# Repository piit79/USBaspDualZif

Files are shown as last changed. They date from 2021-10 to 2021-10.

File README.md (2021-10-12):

# USBaspDualZif

USB in-circuit programmer for Atmel AVR controllers based on USBasp by Thomas Fischl (https://www.fischl.de/usbasp/).

It adds the following extra features:

  * Dual ZIF sockets for ATMega32A-PU and ATMega328p-PU
  * One Cherry MX-compatible switch that acts as the Enter key
  * USB-C socket

Uses mostly SMD components for street cred.

Modified firmware: https://github.com/piit79/USBasp/tree/USBaspDualZif

Released under the [GNU General Public License v2.0](https://raw.githubusercontent.com/piit79/USBaspDualZif/main/LICENSE) (as it's based on USBasp)

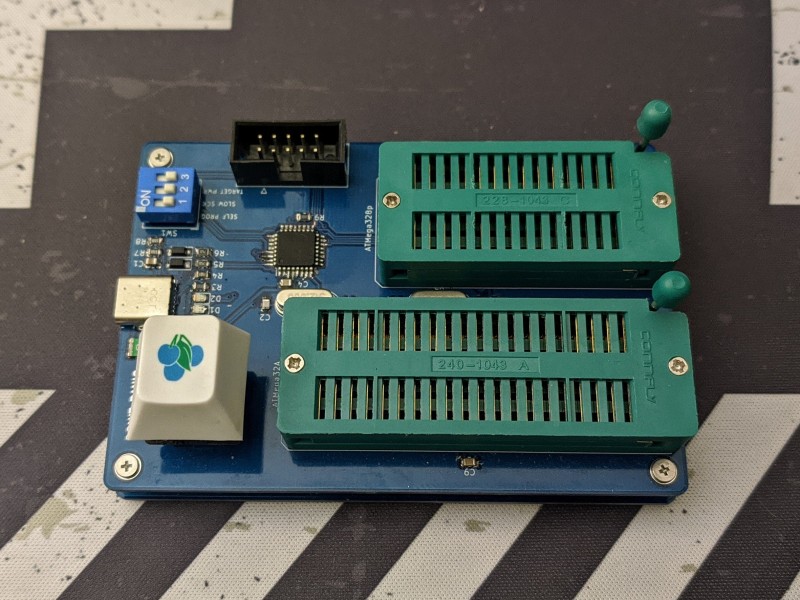
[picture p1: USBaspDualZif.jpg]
USBaspDualZif photo


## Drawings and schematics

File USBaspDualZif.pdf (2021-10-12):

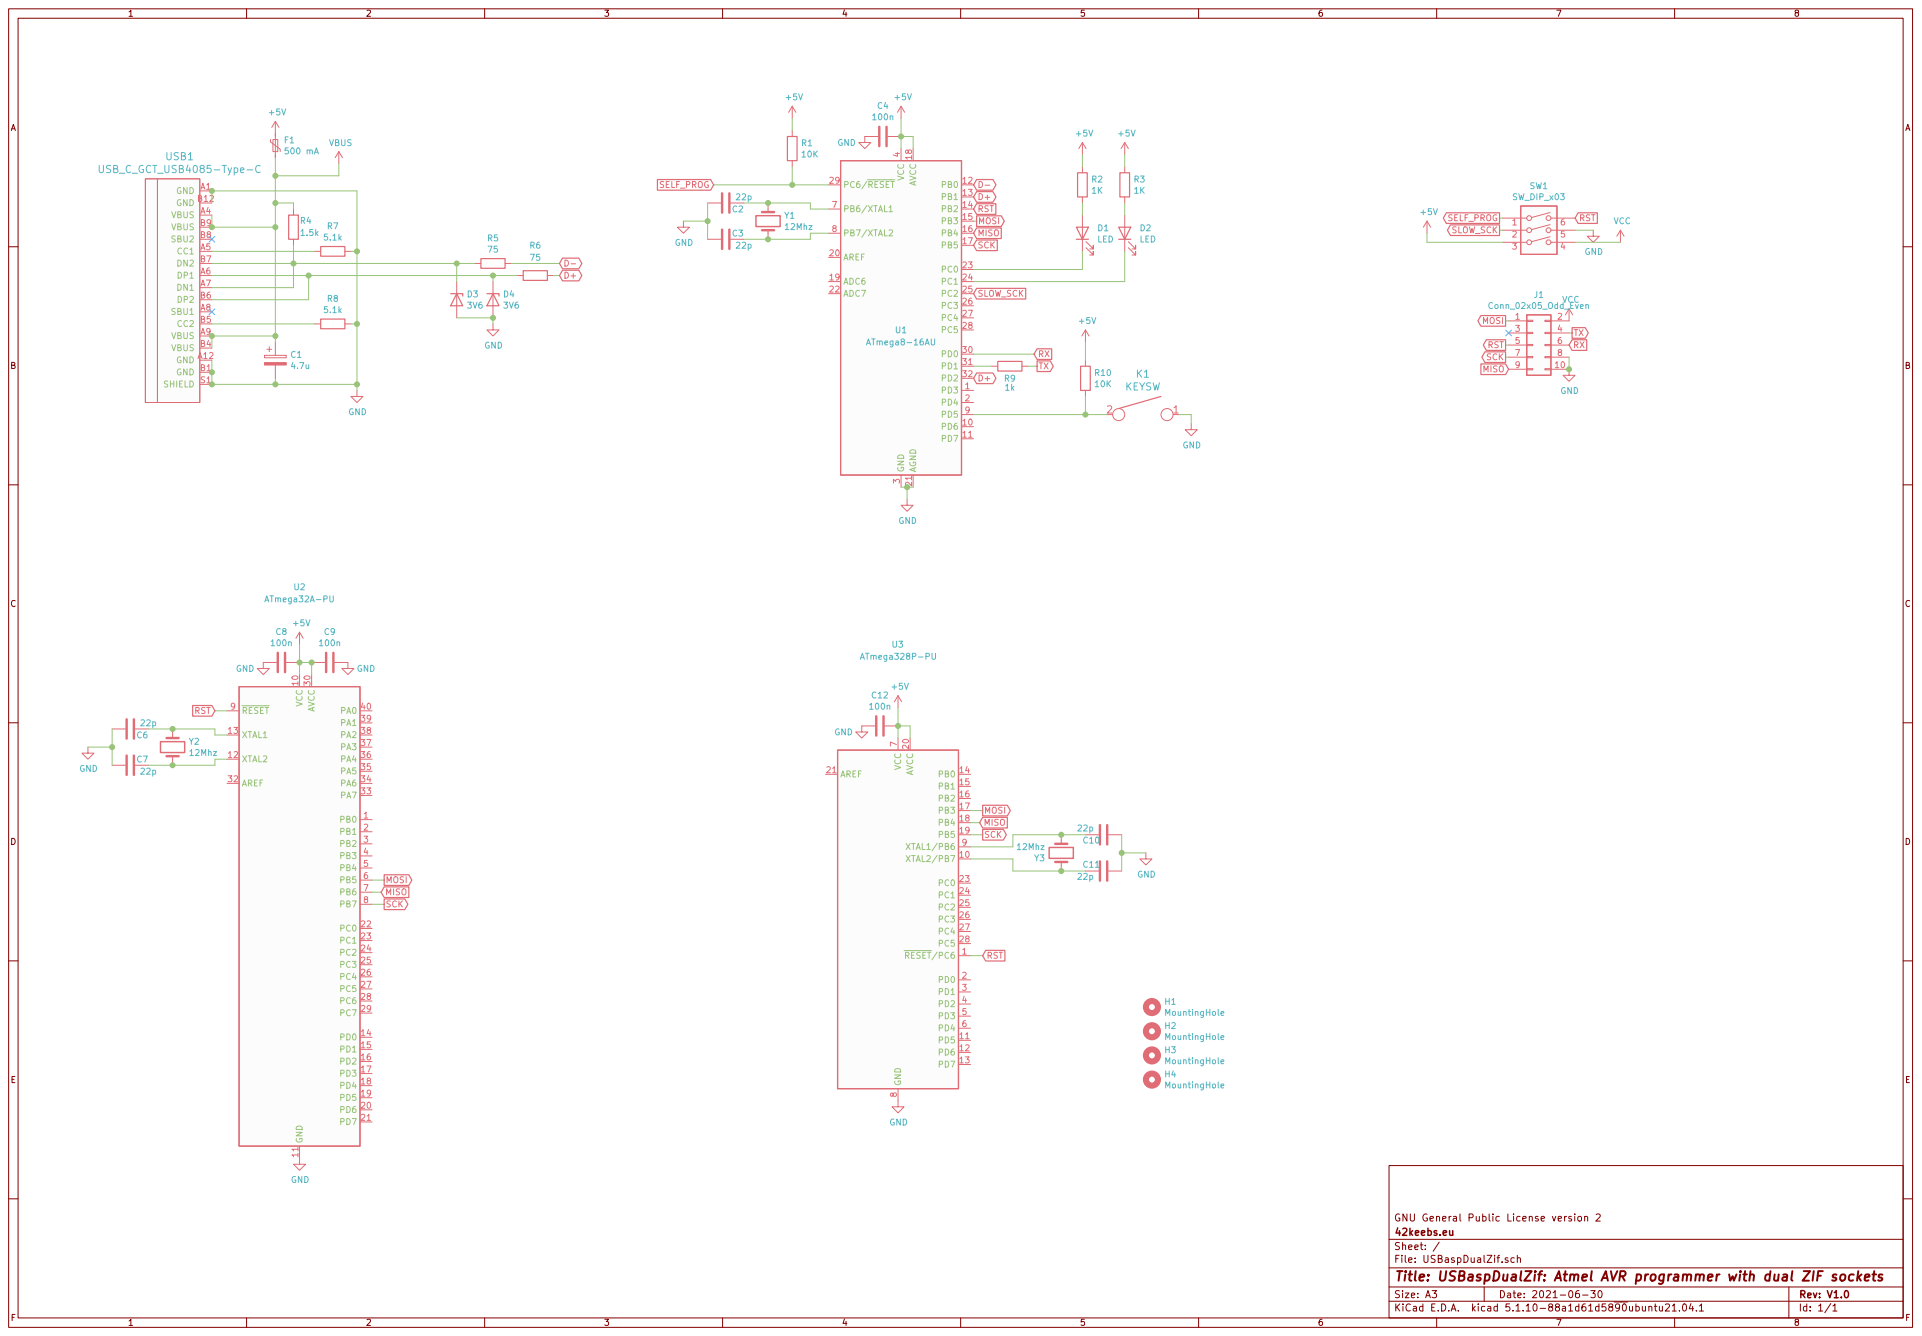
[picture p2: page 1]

File: USBaspDualZif.sch Sheet: / 42keebs.eu GNU General Public License version 2

Id: 1/1 Title: USBaspDualZif: Atmel AVR programmer with dual ZIF sockets

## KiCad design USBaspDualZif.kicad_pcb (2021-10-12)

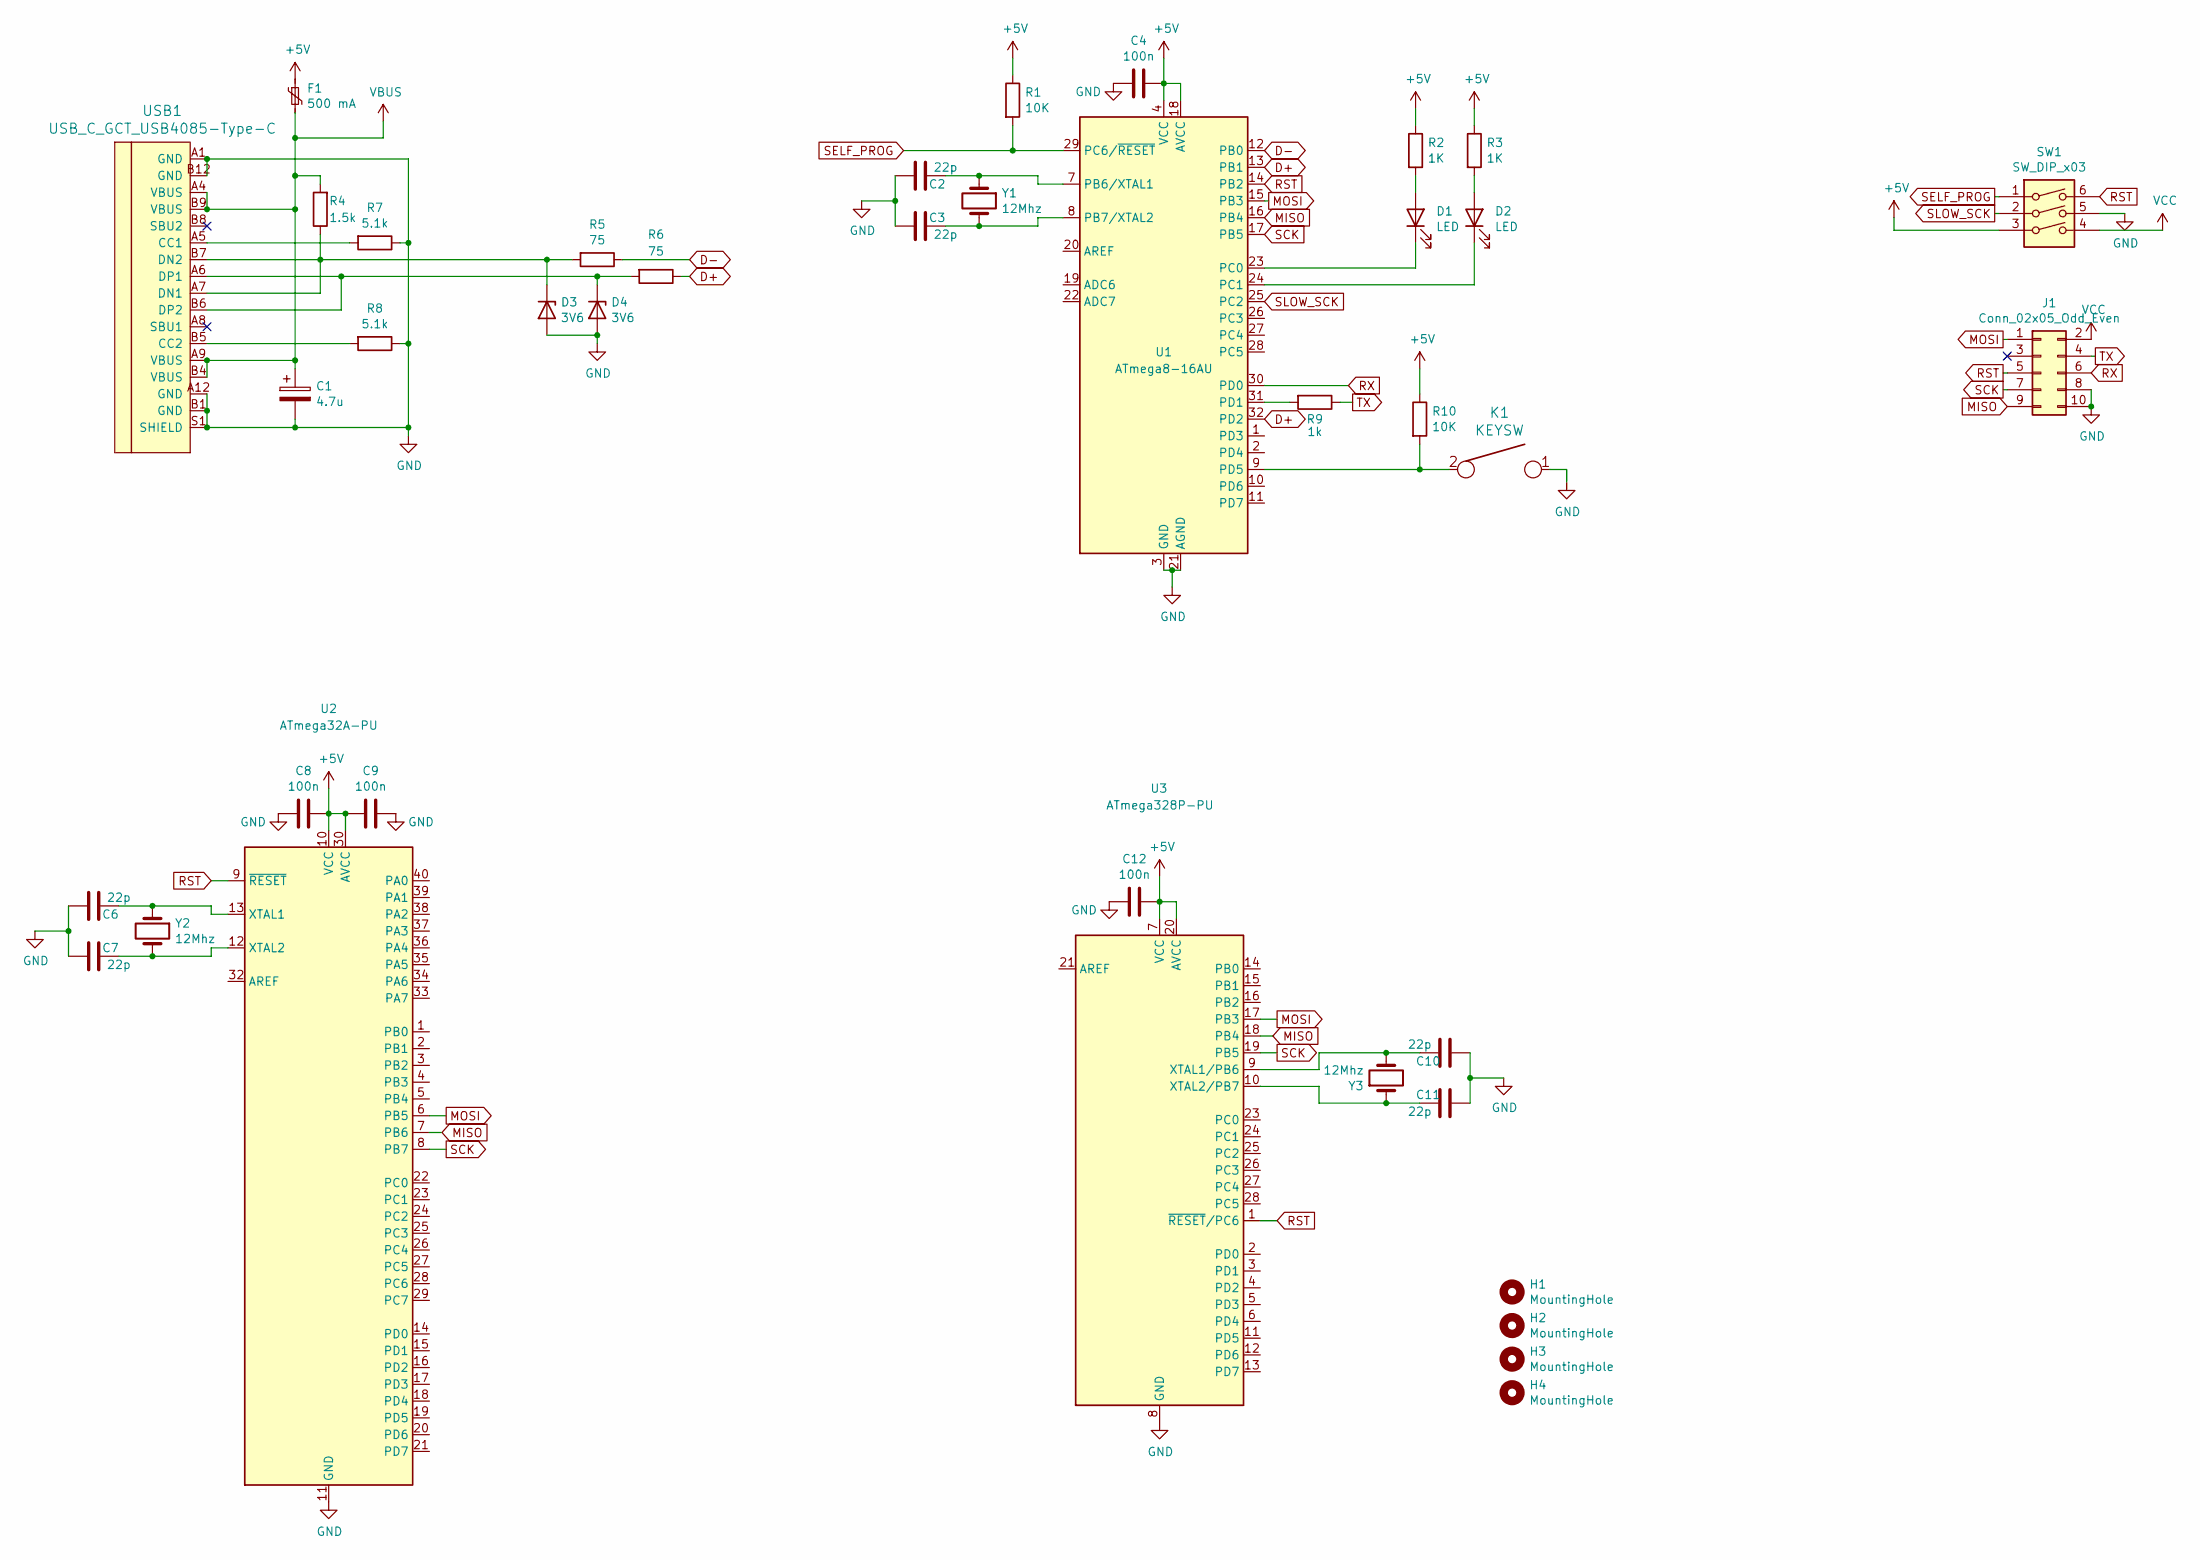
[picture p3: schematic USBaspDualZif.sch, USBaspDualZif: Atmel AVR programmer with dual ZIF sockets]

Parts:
C1: 4.7u; C_0805_2012Metric
C2, C3, C6, C7, C10, C11: 22p; C_0805_2012Metric
C4, C8, C9, C12: 100n; C_0805_2012Metric
D1, D2: LED; LED_0805_2012Metric
D3, D4: 3V6; D_SOD-123
F1: 500 mA; Fuse_1812_4532Metric
H1, H2, H3, H4: MountingHole; MountingHole_2.2mm_M2_Pad
J1: Conn_02x05_Odd_Even; IDC-Header_2x05_P2.54mm_Vertical
K1: KEYSW; SW_Cherry_MX1A_1.00u_PCB-NOSCREEN
R1, R10: 10K; R_0805_2012Metric
R2, R3: 1K; R_0805_2012Metric
R4: 1.5k; R_0805_2012Metric
R5, R6: 75; R_0805_2012Metric
R7, R8: 5.1k; R_0805_2012Metric
R9: 1k; R_0805_2012Metric
SW1: SW_DIP_x03; SW_DIP_SPSTx03_Slide_9.78x9.8mm_W7.62mm_P2.54mm
U1: ATmega8-16AU; TQFP-32_7x7mm_P0.8mm
U2: ATmega32A-PU; 40tex600
U3: ATmega328P-PU; 28tex600
USB1: USB_C_GCT_USB4085-Type-C; USB_C_GCT_USB4085-offset-pads
Y1, Y2, Y3: 12Mhz; Crystal_HC49-4H_Vertical

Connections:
+5V: C4.1, C8.1, C9.2, C12.1, F1.1, R1.1, R2.1, R3.1, R10.1, SW1.3, U1.4 (VCC), U1.6 (VCC), U1.18 (AVCC), U2.10 (VCC), U2.30 (AVCC), U3.7 (VCC), U3.20 (AVCC)
D+: R6.1, U1.13 (PB1), U1.32 (PD2)
D-: R5.1, U1.12 (PB0)
GND: C1.2, C2.2, C3.2, C4.2, C6.2, C7.2, C8.2, C9.1, C10.2, C11.2, C12.2, D3.2 (A), D4.2 (A), J1.8, J1.10, K1.1, R7.1, R8.1, SW1.5, U1.3 (GND), U1.5 (GND), U1.21 (AGND), U2.11 (GND), U2.31 (GND), U3.8 (GND), U3.22 (GND), USB1.A1 (GND), USB1.A12 (GND), USB1.B1 (GND), USB1.B12 (GND), USB1.S1 (SHIELD)
MISO: J1.9, U1.16 (PB4), U2.7 (PB6), U3.18 (PB4)
MOSI: J1.1, U1.15 (PB3), U2.6 (PB5), U3.17 (PB3)
unnamed: C2.1, U1.7 (PB6/XTAL1), Y1.1
unnamed: C3.1, U1.8 (PB7/XTAL2), Y1.2
unnamed: C6.1, U2.13 (XTAL1), Y2.1
unnamed: C7.1, U2.12 (XTAL2), Y2.2
unnamed: C10.1, U3.9 (XTAL1/PB6), Y3.2
unnamed: C11.1, U3.10 (XTAL2/PB7), Y3.1
unnamed: D1.1 (K), U1.23 (PC0)
unnamed: D1.2 (A), R2.2
unnamed: D2.1 (K), U1.24 (PC1)
unnamed: D2.2 (A), R3.2
unnamed: D3.1 (K), R4.1, R5.2, USB1.A7 (DN1), USB1.B7 (DN2)
unnamed: D4.1 (K), R6.2, USB1.A6 (DP1), USB1.B6 (DP2)
unnamed: K1.2, R10.2, U1.9 (PD5)
unnamed: R7.2, USB1.A5 (CC1)
unnamed: R8.2, USB1.B5 (CC2)
unnamed: R9.2, U1.31 (PD1)
RST: J1.5, SW1.6, U1.14 (PB2), U2.9 (~RESET), U3.1 (~RESET~/PC6)
RX: J1.6, U1.30 (PD0)
SCK: J1.7, U1.17 (PB5), U2.8 (PB7), U3.19 (PB5)
SELF_PROG: R1.2, SW1.1, U1.29 (PC6/~RESET)
SLOW_SCK: SW1.2, U1.25 (PC2)
TX: J1.4, R9.1
VBUS: C1.1, F1.2, R4.2, USB1.A4 (VBUS), USB1.A9 (VBUS), USB1.B4 (VBUS), USB1.B9 (VBUS)
VCC: J1.2, SW1.4

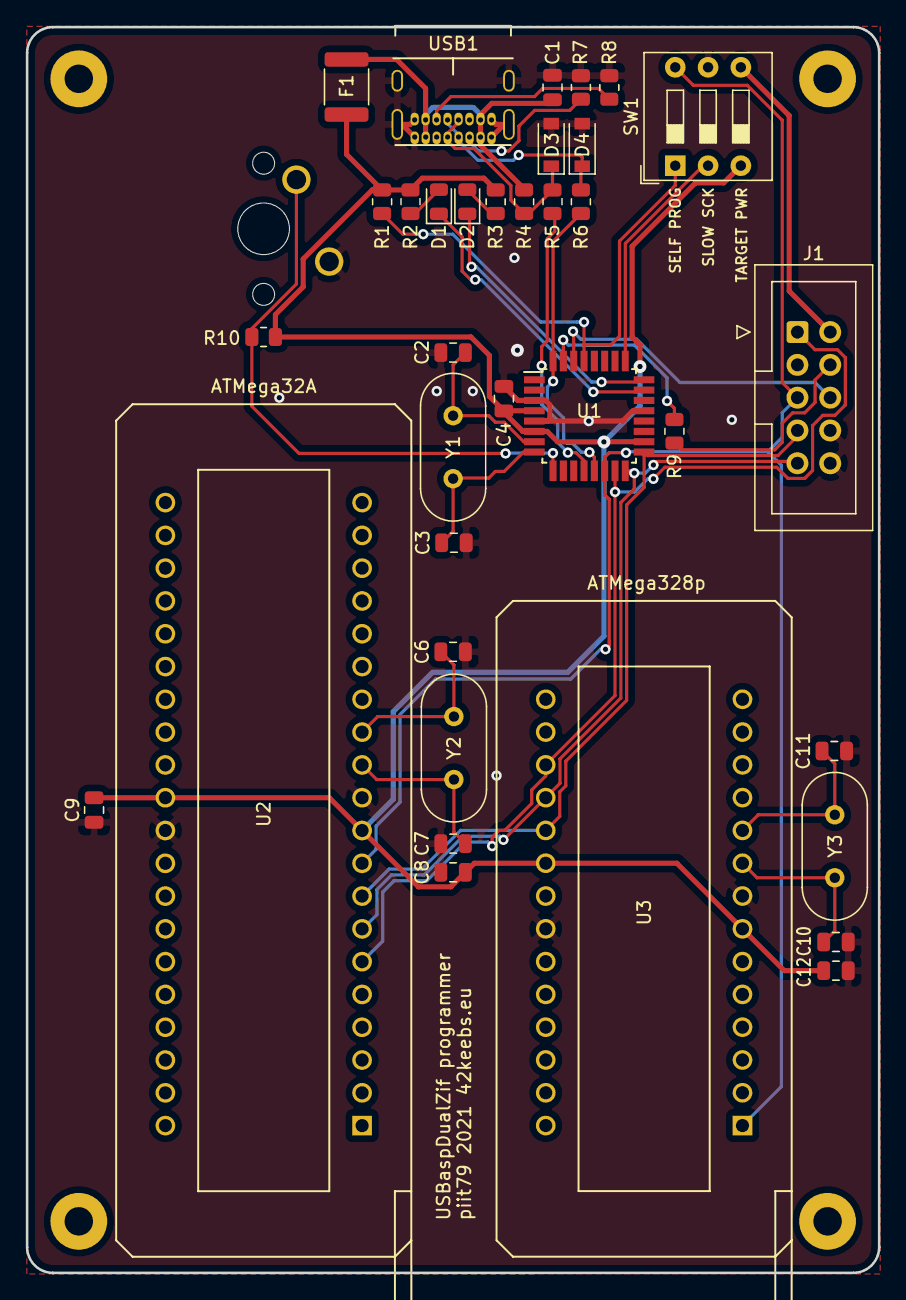
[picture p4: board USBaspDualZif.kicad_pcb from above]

Board: 2 copper layers, 66.0 x 96.5 mm, 40 parts (0 on the bottom side), 30 nets.

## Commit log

2021-10-12 Add KiCad files
    [USBaspDualZif-bottom.kicad_pcb, USBaspDualZif.kicad_pcb, USBaspDualZif.sch]
2021-10-12 Add Gerber files
    [USBaspDualZif-B_Cu.gbr, USBaspDualZif-B_Mask.gbr, USBaspDualZif-B_Paste.gbr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]
